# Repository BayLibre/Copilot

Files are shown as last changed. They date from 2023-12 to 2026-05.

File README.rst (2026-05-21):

Copilot
=======

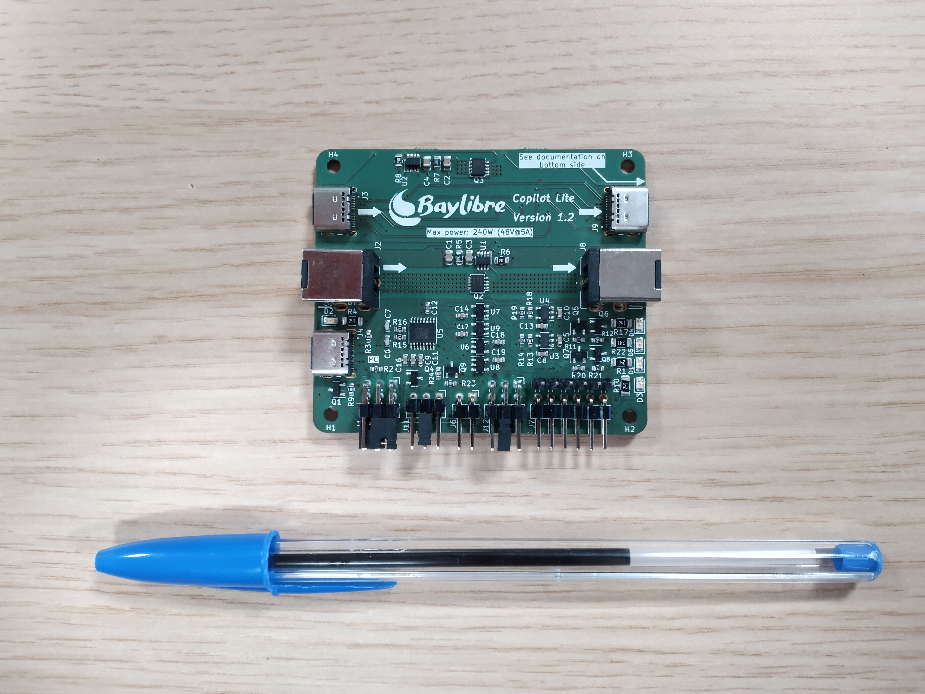
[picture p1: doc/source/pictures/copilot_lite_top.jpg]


Description
-----------

The user documentation is available in the ``doc`` folder.
The generated HTML pages can be viewed `here <https://baylibre.github.io/Copilot/>`_.

The board hardware files are in the ``Copilot_Lite/Hardware`` folder.

The FTDI chip is configured and serialized by the ``Serialization`` software located in the  ``Copilot_Lite/Software`` folder.
The boards serialization and test procedure is described in the ``Copilot_Lite/Factory_Testing.md`` file.

Doc build instructions
----------------------

Using python3, do:

.. code-block:: console

   $ pip3 install -U sphinx sphinx-rtd-theme sphinx-prompt

Then rebuild with:

.. code-block:: console

   $ cd doc
   $ make html

The build output is located in ``doc/build/html/``. Open it with:

.. code-block:: console

   $ xdg-open doc/build/html/index.html

Tips and tricks
---------------

To find a reference to another section, use:

.. code-block:: console

   $ python -m sphinx.ext.intersphinx doc/build/html/objects.inv

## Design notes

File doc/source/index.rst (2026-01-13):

.. Copilot documentation master file, created by
   sphinx-quickstart on Tue Dec 12 19:07:24 2023.
   You can adapt this file completely to your liking, but it should at least
   contain the root `toctree` directive.

Welcome to Copilot's documentation!
===================================

Copilot is a small device used to control the power and UART of a Device Under
Test (DUT). Copilot is controlled and powered by a PC using a single USB-C
connection. It controls the DUT power supply through either another USB-C
connection or a barrel jack connection.

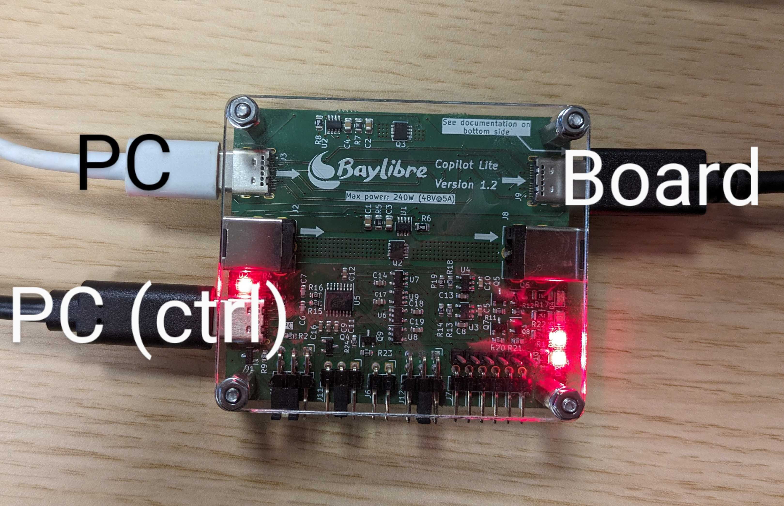
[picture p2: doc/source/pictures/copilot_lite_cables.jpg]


Features
--------

 - Power switching with a simple command available in many distributions:

   .. prompt:: bash

     gpioset /dev/copilot/by-id/${ID_USB_SERIAL_SHORT}/gpiochip 0=1

 - Switch power up to 48V/5A via USB-C or Power Jack
 - Connect to DUT UART on 1.8/3.3/5V
 - Provide 3 additional GPIOs for other DUT related tasks

.. toctree::
   :maxdepth: 2
   :caption: Documentation:

   getting-started
   tips-and-tricks
   technical-information

Indices and tables
==================

* :ref:`genindex`
* :ref:`modindex`
* :ref:`search`

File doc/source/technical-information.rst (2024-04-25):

Technical information
=====================

Barrel jack power channel
-------------------------

- The Barrel jack power channel is rated for 48V @ 5A without additional
  cooling (at a normal room temperature). A higher power **has not been
  tested** and might blow up your Copilot board, it also may need additional
  cooling.
- The barrel jacks dimensions are 2.1x5.5mm.
- Connectors polarity: the barrel jack outer contact is GND, the center pin is
  a positive voltage.
- Voltage polarity must not be reversed, and a negative voltage on the barrel
  jack center pin is forbidden.
- The minimum allowed voltage on this channel is +5V.
- If a voltage greater than or equal to 53.3V is applied to the jack channel,
  the power transistor will open thanks to an overvoltage protection. The
  Copilot board needs to be fully reset to be used again (by removing all jack
  and USB-C cables connected to the Copilot board and then reconnecting them).

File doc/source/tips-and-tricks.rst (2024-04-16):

Tips and tricks
===============

Creating your own jack cable
----------------------------

Given the differences between barrel jack connectors (both the inside and
outside diameter) and the difficulty distinguishing between them, it may
make more sense to create a custom cable.

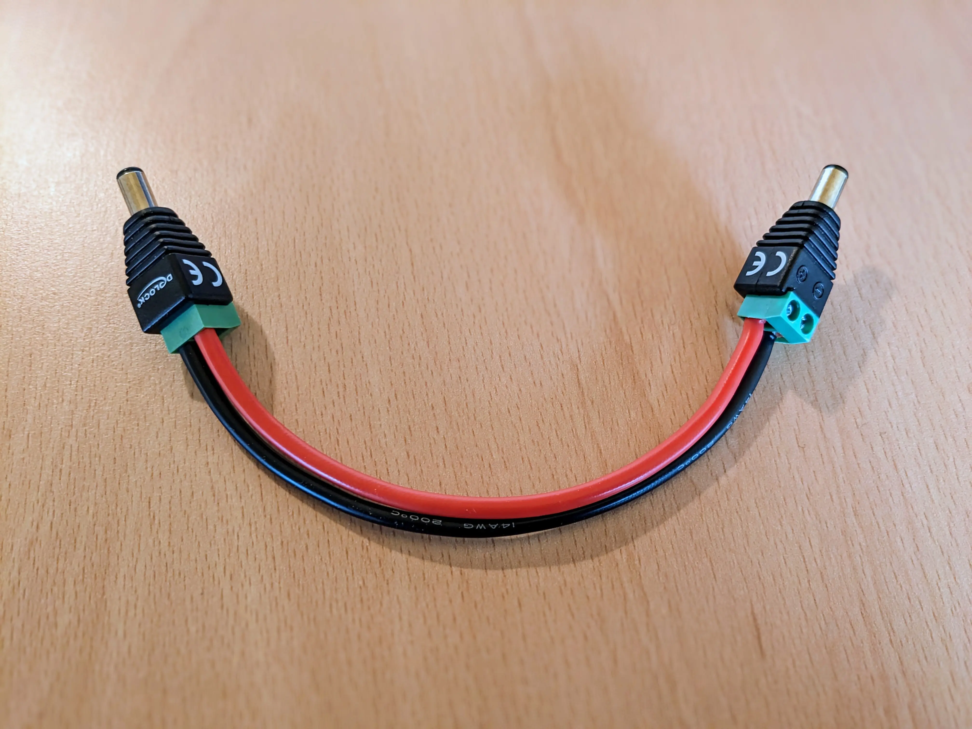
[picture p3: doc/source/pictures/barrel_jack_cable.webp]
   

For example, a cable can be created using two barrel jack male connectors with
screw terminals. It is possible for some 2.1x5.5mm barrel jack connectors to also
work with 2.5x5.5mm female connectors.

The recommended diameter of the wire connecting the two adapters is 2.5mm² or
14 AWG, so that they will be able to carry the power with a minimized
resistance. You are of course free to use whatever cable you want that suits
your needs according to the load you are powering.

It is also recommended to keep the cable length as short as possible for the
designated task to minimize its resistance.

The connector ``CLEVER LITTLE BOX CLB-JL-52Y`` has been tested and holds up to
250W without issue or too much overheating.

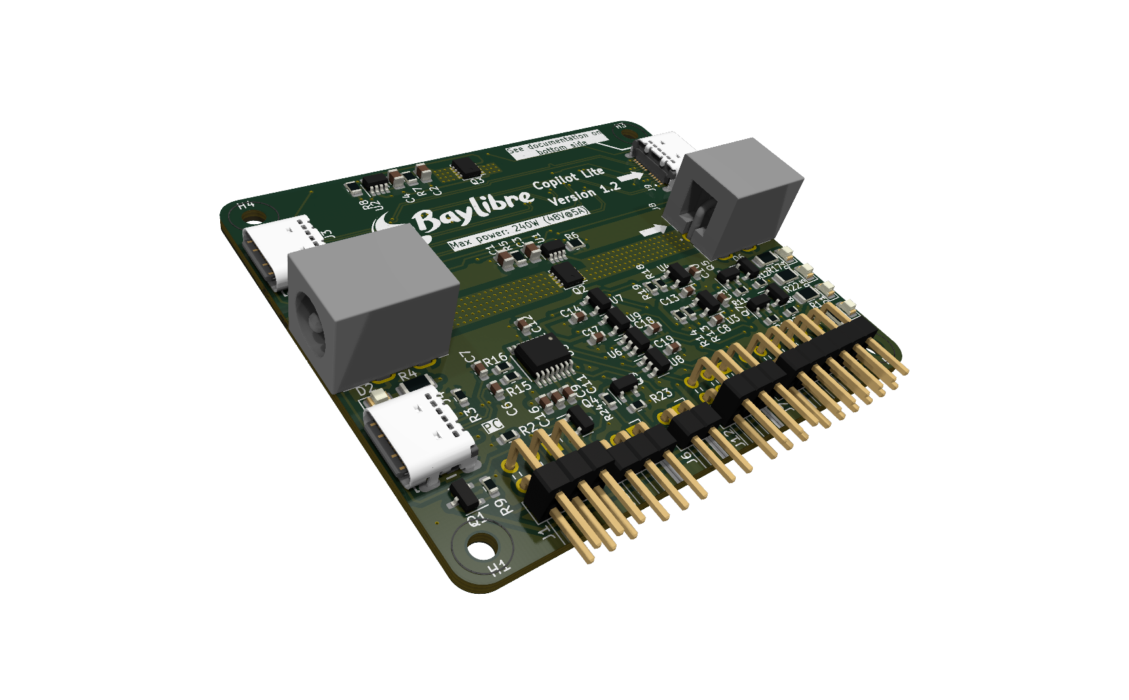
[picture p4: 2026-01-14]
doc/source/pictures/copilot_lite_3d_side.png

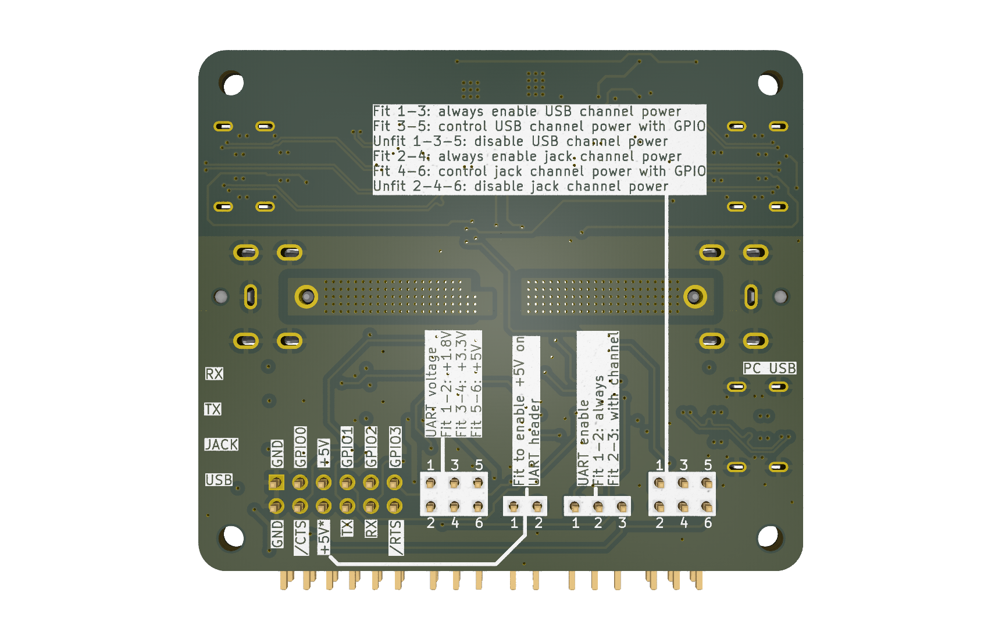
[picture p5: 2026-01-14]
doc/source/pictures/copilot_lite_3d_bottom.png

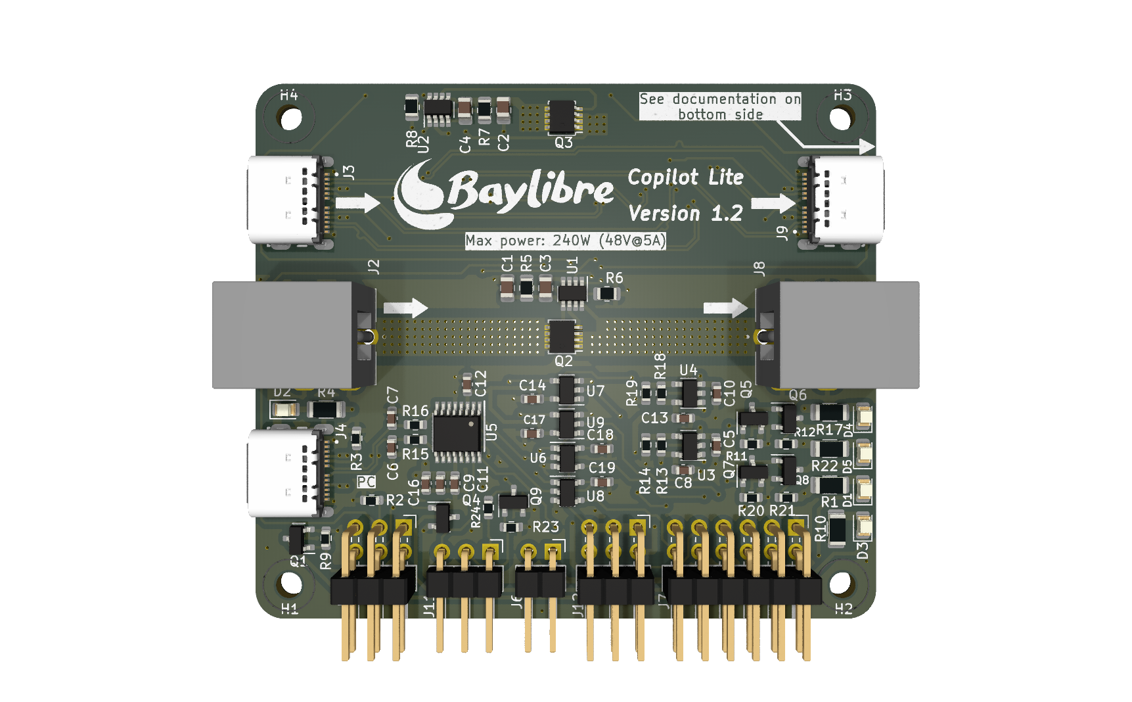
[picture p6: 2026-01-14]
doc/source/pictures/copilot_lite_3d_top.png

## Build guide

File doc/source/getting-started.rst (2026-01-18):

Getting started
===============

Hardware setup
--------------

To use Copilot, you need:

- A Copilot
- 1 USB-C cable for control (only USB2 wiring needed)

Optionally, depending on your needs:

- 2 USB-C cables for power (power supply ↔ Copilot ↔ DUT)
- 2 Barrel jack cables for additional power supply
- 3+ wires for FTDI (debug UART)
- Wires for additional GPIOs

Plug it in as following:



.. note::

   By default, the USB and barrel jack power passthroughs are controlled by a
   single GPIO. To enable the USB and barrel jack power passthroughs follow
   the steps in :ref:`Switch power`.

.. warning::

   Even if USB-C is a **reversible** connector, the USB-C cables can only work
   in **one direction**.  If USB power supply seems not working after enabling.
   Try flipping one USB-C cable on either ``J9`` or ``J3``.

.. warning::

   Copilot is not designed to support power passthrough through the USB and
   barrel jack connectors at the same time. It is therefore good practice to
   only jump a single pair of pins at a time

Basic documentation has been silk screened onto both sides of the board.

Design files, along with the latest schematics and the interactive BOM,
are manually generated for each release and available on the
`releases page <https://github.com/BayLibre/Copilot/releases>`_.
The interactive BOM features an annotated diagram of the board
including the silk screen, both sides of the board and searchable references.

Udev rules
----------

Generally, a PC running Linux has multiple GPIOs in the system. To easily
identify Copilot, create some user-friendly symlinks with udev as follows.

#. Add the ``/etc/udev/rules.d/70-copilot.rules`` udev rules to your system:

   .. code-block::

     ACTION=="remove", GOTO="copilot_end"

     # Match Copilot USB devices
     SUBSYSTEMS=="usb", ATTRS{manufacturer}=="Bay[lL]ibre", ATTRS{product}=="Bay[lL]ibre Copilot*", ENV{IS_COPILOT}="1", ENV{ID_USB_SERIAL_SHORT}="$attr{serial}"
     # Enable Copilot gpio access via uaccess and copilot symlink
     ENV{IS_COPILOT}=="1", SUBSYSTEMS=="gpio", MODE="0660", SYMLINK+="copilot/by-id/$env{ID_USB_SERIAL_SHORT}/gpiochip", TAG+="uaccess"
     # Create Copilot tty symlink
     ENV{IS_COPILOT}=="1", SUBSYSTEMS=="tty", SYMLINK+="copilot/by-id/$env{ID_USB_SERIAL_SHORT}/tty"

     LABEL="copilot_end"

   .. note::

     For users who rely on the ``plugdev`` group, use the following rules
     instead:

     .. code-block::

         # Match Copilot USB devices
         SUBSYSTEMS=="usb", ATTRS{manufacturer}=="Bay[lL]ibre", ATTRS{product}=="Bay[lL]ibre Copilot*", ENV{IS_COPILOT}="1", ENV{ID_USB_SERIAL_SHORT}="$attr{serial}"
         # Enable Copilot gpio access for the plugdev group and copilot symlink
         ENV{IS_COPILOT}=="1", SUBSYSTEMS=="gpio", MODE="0660", GROUP="plugdev", SYMLINK+="copilot/by-id/$env{ID_USB_SERIAL_SHORT}/gpiochip"
         # Create Copilot tty symlink
         ENV{IS_COPILOT}=="1", SUBSYSTEMS=="tty", SYMLINK+="copilot/by-id/$env{ID_USB_SERIAL_SHORT}/tty"

     ``uaccess`` should be used instead of ``plugdev``. For more information,
     see: https://github.com/systemd/systemd/issues/4288

#. Reload the udev rules with:

  .. prompt:: bash $

     sudo udevadm control --reload
     sudo udevadm trigger

This creates an entry in ``/dev/copilot/by-id/<copilot_id>`` where
``<copilot_id>`` is an unique serial number.

.. _Switch power:

Switch power
------------

Now that the udev rules have been installed, we can interact with Copilot using the
standard ``libgpiod-utils``, such as ``gpioset``.

Start by finding the serial number for your Copilot (e.g. ``D30HF04Y``) and
export it as an environment variable:

.. prompt:: bash $ auto

   $ tree /dev/copilot/
   /dev/copilot/
   └── by-id
       └── D30HF04Y
           ├── gpiochip -> ../../../gpiochip0
           └── tty -> ../../../ttyUSB1
   $ export ID_USB_SERIAL_SHORT="D30HF04Y"

Power over the USB and barrel jack connectors may be independently configured
using the J1 header to be either controlled by a single shared GPIO or always
passthrough power. See the silk screen at the top of the rear side of the
board.

By default, the USB and barrel jack power passthroughs are controlled by your
PC using a single GPIO that is disabled after power cycling Copilot. The
passthroughs can be powered by enabling the GPIO as follows:

.. prompt:: bash $

   gpioset --hold-period=20ms -t0 --chip /dev/copilot/by-id/${ID_USB_SERIAL_SHORT}/gpiochip 0=1

.. note::

   For older versions of ``libgpiod-utils``, (before v2.0), use the following
   instead:

   .. prompt:: bash $

      gpioset /dev/copilot/by-id/${ID_USB_SERIAL_SHORT}/gpiochip 0=1

To disable the barrel jack power passthrough, use ``0=0`` instead:

.. prompt:: bash $

   gpioset --hold-period=20ms -t0 --chip /dev/copilot/by-id/${ID_USB_SERIAL_SHORT}/gpiochip 0=0

Helper script
~~~~~~~~~~~~~

``copilot.sh`` is an example helper script which can either reboot or power off
a board connected to Copilot.

It can be used with:

.. prompt:: bash $ auto

   # to reboot
   $ copilot.sh reboot
   # to poweroff
   $ copilot.sh poweroff

The contents of ``copilot.sh`` could be as following:

.. code-block:: bash

   #!/bin/bash

   # Set a default value, but don't overwrite ID_USB_SERIAL_SHORT
   # if it's already set
   : ${ID_USB_SERIAL_SHORT:="D30HF04Y"}

   usage()
   {
       echo "Usage: ${0##*/} reboot|poweroff"
   }

   if [[ $# -ne 1 ]]; then
       usage
       exit 1
   fi

   do_poweroff()
   {
       gpioset --hold-period=20ms -t0 --chip /dev/copilot/by-id/${ID_USB_SERIAL_SHORT}/gpiochip 0=0
       # or for libgpiod v < 2.0
       #gpioset /dev/copilot/by-id/${ID_USB_SERIAL_SHORT}/gpiochip 0=0
   }

   do_poweron()
   {
       gpioset --hold-period=20ms -t0 --chip /dev/copilot/by-id/${ID_USB_SERIAL_SHORT}/gpiochip 0=1
       # or for libgpiod v < 2.0
       #gpioset /dev/copilot/by-id/${ID_USB_SERIAL_SHORT}/gpiochip 0=1
   }

   do_reboot()
   {
       do_poweroff
       # maybe wait until all power drained from the board
       #sleep 5
       do_poweron
   }

   case "$1" in
       "reboot") do_reboot;;
       "poweroff") do_poweroff;;
       *) usage; exit 1;;

   esac

Connect to a UART
-----------------

Connect to the Copilot UART using the left-most header at the bottom of
the PCB (J4). The pins are documented on the bottom of the PCB. The voltage can
be selected on the next header.

To use the connected UART in Linux you can use your favorite terminal program
with the device ``/dev/copilot/by-id/${ID_USB_SERIAL_SHORT}/tty``, in this
example we are using ``tio``:

.. prompt:: bash

   tio /dev/copilot/by-id/${ID_USB_SERIAL_SHORT}/tty

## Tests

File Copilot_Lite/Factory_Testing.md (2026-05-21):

# Factory testing

The board comes from the factory, fully assembled but without any jumper.  

The test setup is made of :

* A Linux PC running Debian
* An USB 3.x/2.0 hub.
* Two USB-C cables, one of them being *USB 3.x* compliant. The second one can be only *USB 2.0* compliant.

## Serialization
1. On the PC, run `sudo dmesg -wH` in a terminal.
2. Connect the PC to the board `PC USB (J4)` connector through an USB-C cable (the cable can either be *USB 3.x* or *USB 2.0* compliant).
    1. The `PC USB (D2)` LED must light.
    2. The PC must detect a `FT230X Basic UART`.
3. Disconnect the USB-C cable from the board only, flip it face-to-down and reconnect it to the board `PC USB` connector. The result must be identical to the previous step.
4. Run the serialization tool with the command `sudo Copilot/Copilot_Lite/Software/Serialization/copilot-lite-serialize`.
5. Disconnect and reconnect the USB-C cable from the board `PC USB` connector. The `dmesg` output must now display a `BayLibre Copilot Lite Vx.y` product.
6. Make sure that the serialized version is matching the version written on the board PCB silkscreen.

You can close the terminal displaying the kernel console output once all boards have been successfully serialized.

## USB 3.0 passthrough

1. On the PC, run `sudo dmesg -wH | grep -i -e superspeed -e high-speed` in a terminal.
2. Fit a jumper between pins 1 and 3 of the board `J1` pin header.
3. Connect the board `PC USB (J4)` connector to the PC with an USB-C cable.
    1. The `PC USB (D2)` LED must light.
    2. The `USB (D3)` LED must light.
4. Connect an *USB 3.x* USB hub to the `J9` USB-C connector.
5. Connect a second USB-C cable from the PC to the board `J3` USB-C connector. Note that the cable **must** be *USB 3.x* compliant in order to the whether the board *USB 3.0* SuperSpeed pairs are working.
6. There are only two board USB-C connectors orientation that allow the power and the data to go through. Flip the `J3` and the `J9` cable orientation one after the other, the USB hub must be detected in two of the four possible combinations.
7. Each time that the USB hub is detected, make sure that the PC kernel console is detecting both *SuperSpeed* and *high-speed* internal USB hubs. This proves that either the *USB 3.0* and the *USB 2.0* board signals are working.

## Connecting jumpers

1. Remove any testing jumper from the board.
2. `J1` pin header :
    1. Fit a jumper horizontally between pins 3 and 5.
    2. Fit a jumper horizontally between pins 4 and 6.
3. `J11` pin header :
    1. Fit a jumper horizontally between pins 2 and 3.
4. `J12` pin header :
    1. Fit a jumper vertically between pins 3 and 4.

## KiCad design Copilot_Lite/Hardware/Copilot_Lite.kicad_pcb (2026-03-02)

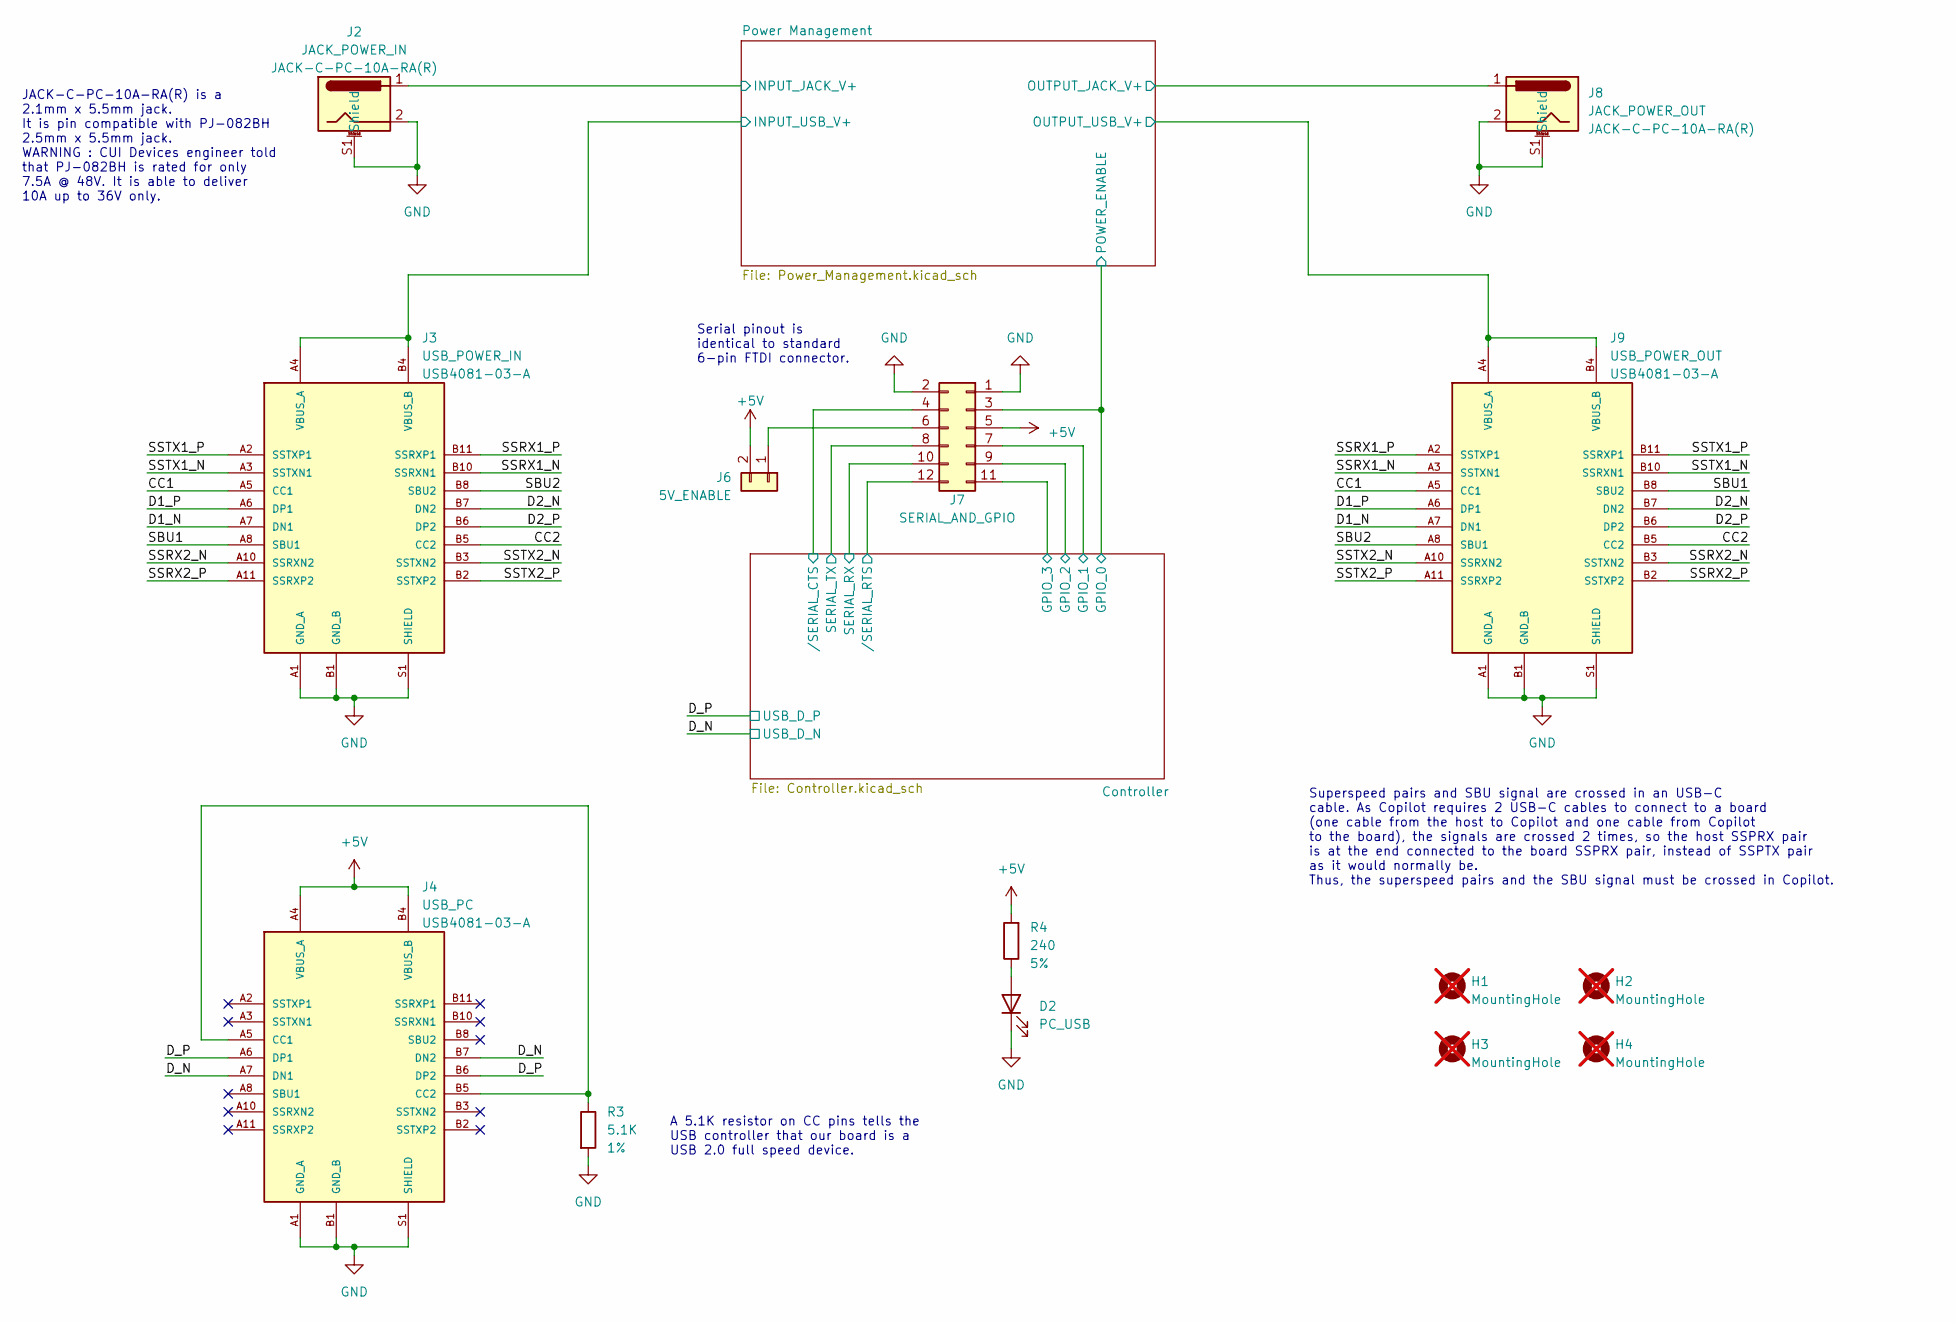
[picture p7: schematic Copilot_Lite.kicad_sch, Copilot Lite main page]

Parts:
D2: PC_USB; LED_0805_2012Metric; PartNumber 150080SS75000
H1, H2, H3, H4: MountingHole; MountingHole_2.7mm; not fitted
J2: JACK_POWER_IN; JACK-C-PC-10A-RA(R); PartNumber JACK-C-PC-10A-RA(R)
J3: USB_POWER_IN; USB4081-03-A; PartNumber USB4081-03-A
J4: USB_PC; USB4081-03-A; PartNumber USB4081-03-A
J6: 5V_ENABLE; PinHeader_1x02_P2.54mm_Horizontal
J7: SERIAL_AND_GPIO; PinHeader_2x06_P2.54mm_Horizontal
J8: JACK_POWER_OUT; JACK-C-PC-10A-RA(R); PartNumber JACK-C-PC-10A-RA(R)
J9: USB_POWER_OUT; USB4081-03-A; PartNumber USB4081-03-A
R3: 5.1K; R_0603_1608Metric; PartNumber RC0603FR-075K1L
R4: 240; R_1206_3216Metric; PartNumber RC1206JR-07240RL

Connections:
+5V: J4.A4 (VBUS_A), J4.A9 (VBUS_A), J4.B4 (VBUS_B), J4.B9 (VBUS_B), J6.2, J7.5, R4.2; also elsewhere on the board
/CC1: J3.A5 (CC1), J9.A5 (CC1)
/CC2: J3.B5 (CC2), J9.B5 (CC2)
/Controller/GPIO_0: J7.3; also elsewhere on the board
/Controller/GPIO_1: J7.7; also elsewhere on the board
/Controller/GPIO_2: J7.9; also elsewhere on the board
/Controller/GPIO_3: J7.11; also elsewhere on the board
/Controller/SERIAL_RX: J7.10; also elsewhere on the board
/Controller/SERIAL_TX: J7.8; also elsewhere on the board
/Controller//SERIAL_CTS: J7.4; also elsewhere on the board
/Controller//SERIAL_RTS: J7.12; also elsewhere on the board
/D1_N: J3.A7 (DN1), J9.A7 (DN1)
/D1_P: J3.A6 (DP1), J9.A6 (DP1)
/D2_N: J3.B7 (DN2), J9.B7 (DN2)
/D2_P: J3.B6 (DP2), J9.B6 (DP2)
/D_N: J4.A7 (DN1), J4.B7 (DN2); also elsewhere on the board
/D_P: J4.A6 (DP1), J4.B6 (DP2); also elsewhere on the board
/Power Management/INPUT_JACK_V+: J2.1; also elsewhere on the board
/Power Management/INPUT_USB_V+: J3.A4 (VBUS_A), J3.A9 (VBUS_A), J3.B4 (VBUS_B), J3.B9 (VBUS_B); also elsewhere on the board
/Power Management/OUTPUT_JACK_V+: J8.1; also elsewhere on the board
/Power Management/OUTPUT_USB_V+: J9.A4 (VBUS_A), J9.A9 (VBUS_A), J9.B4 (VBUS_B), J9.B9 (VBUS_B); also elsewhere on the board
/SBU1: J3.A8 (SBU1), J9.B8 (SBU2)
/SBU2: J3.B8 (SBU2), J9.A8 (SBU1)
/SSRX1_N: J3.B10 (SSRXN1), J9.A3 (SSTXN1)
/SSRX1_P: J3.B11 (SSRXP1), J9.A2 (SSTXP1)
/SSRX2_N: J3.A10 (SSRXN2), J9.B3 (SSTXN2)
/SSRX2_P: J3.A11 (SSRXP2), J9.B2 (SSTXP2)
/SSTX1_N: J3.A3 (SSTXN1), J9.B10 (SSRXN1)
/SSTX1_P: J3.A2 (SSTXP1), J9.B11 (SSRXP1)
/SSTX2_N: J3.B3 (SSTXN2), J9.A10 (SSRXN2)
/SSTX2_P: J3.B2 (SSTXP2), J9.A11 (SSRXP2)
GND: D2.1 (K), J2.2, J2.S1 (Shield), J2.S2 (Shield), J2.S3 (Shield), J2.S4 (Shield), J3.A1 (GND_A), J3.A12 (GND_A), J3.B1 (GND_B), J3.B12 (GND_B), J3.S1 (SHIELD), J3.S2 (SHIELD), J3.S3 (SHIELD), J3.S4 (SHIELD), J3.S5 (SHIELD), J3.S6 (SHIELD), J4.A1 (GND_A), J4.A12 (GND_A), J4.B1 (GND_B), J4.B12 (GND_B), J4.S1 (SHIELD), J4.S2 (SHIELD), J4.S3 (SHIELD), J4.S4 (SHIELD), J4.S5 (SHIELD), J4.S6 (SHIELD), J7.1, J7.2, J8.2, J8.S1 (Shield), J8.S2 (Shield), J8.S3 (Shield), J8.S4 (Shield), J9.A1 (GND_A), J9.A12 (GND_A), J9.B1 (GND_B), J9.B12 (GND_B), J9.S1 (SHIELD), J9.S2 (SHIELD), J9.S3 (SHIELD), J9.S4 (SHIELD), J9.S5 (SHIELD), J9.S6 (SHIELD), R3.2; also elsewhere on the board
unnamed: D2.2 (A), R4.1
unnamed: J4.A5 (CC1), J4.B5 (CC2), R3.1
unnamed: J6.1, J7.6

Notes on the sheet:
A 5.1K resistor on CC pins tells the USB controller that our board is a USB 2.0 full speed device.
JACK-C-PC-10A-RA(R) is a 2.1mm x 5.5mm jack. It is pin compatible with PJ-082BH 2.5mm x 5.5mm jack. WARNING : CUI Devices engineer told that PJ-082BH is rated for only 7.5A @ 48V. It is able to deliver 10A up to 36V only.
Superspeed pairs and SBU signal are crossed in an USB-C cable. As Copilot requires 2 USB-C cables to connect to a board (one cable from the host to Copilot and one cable from Copilot to the board), the signals are crossed 2 times, so the host SSPRX pair is at the end connected to the board SSPRX pa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
Serial pinout is identical to standard 6-pin FTDI connector.

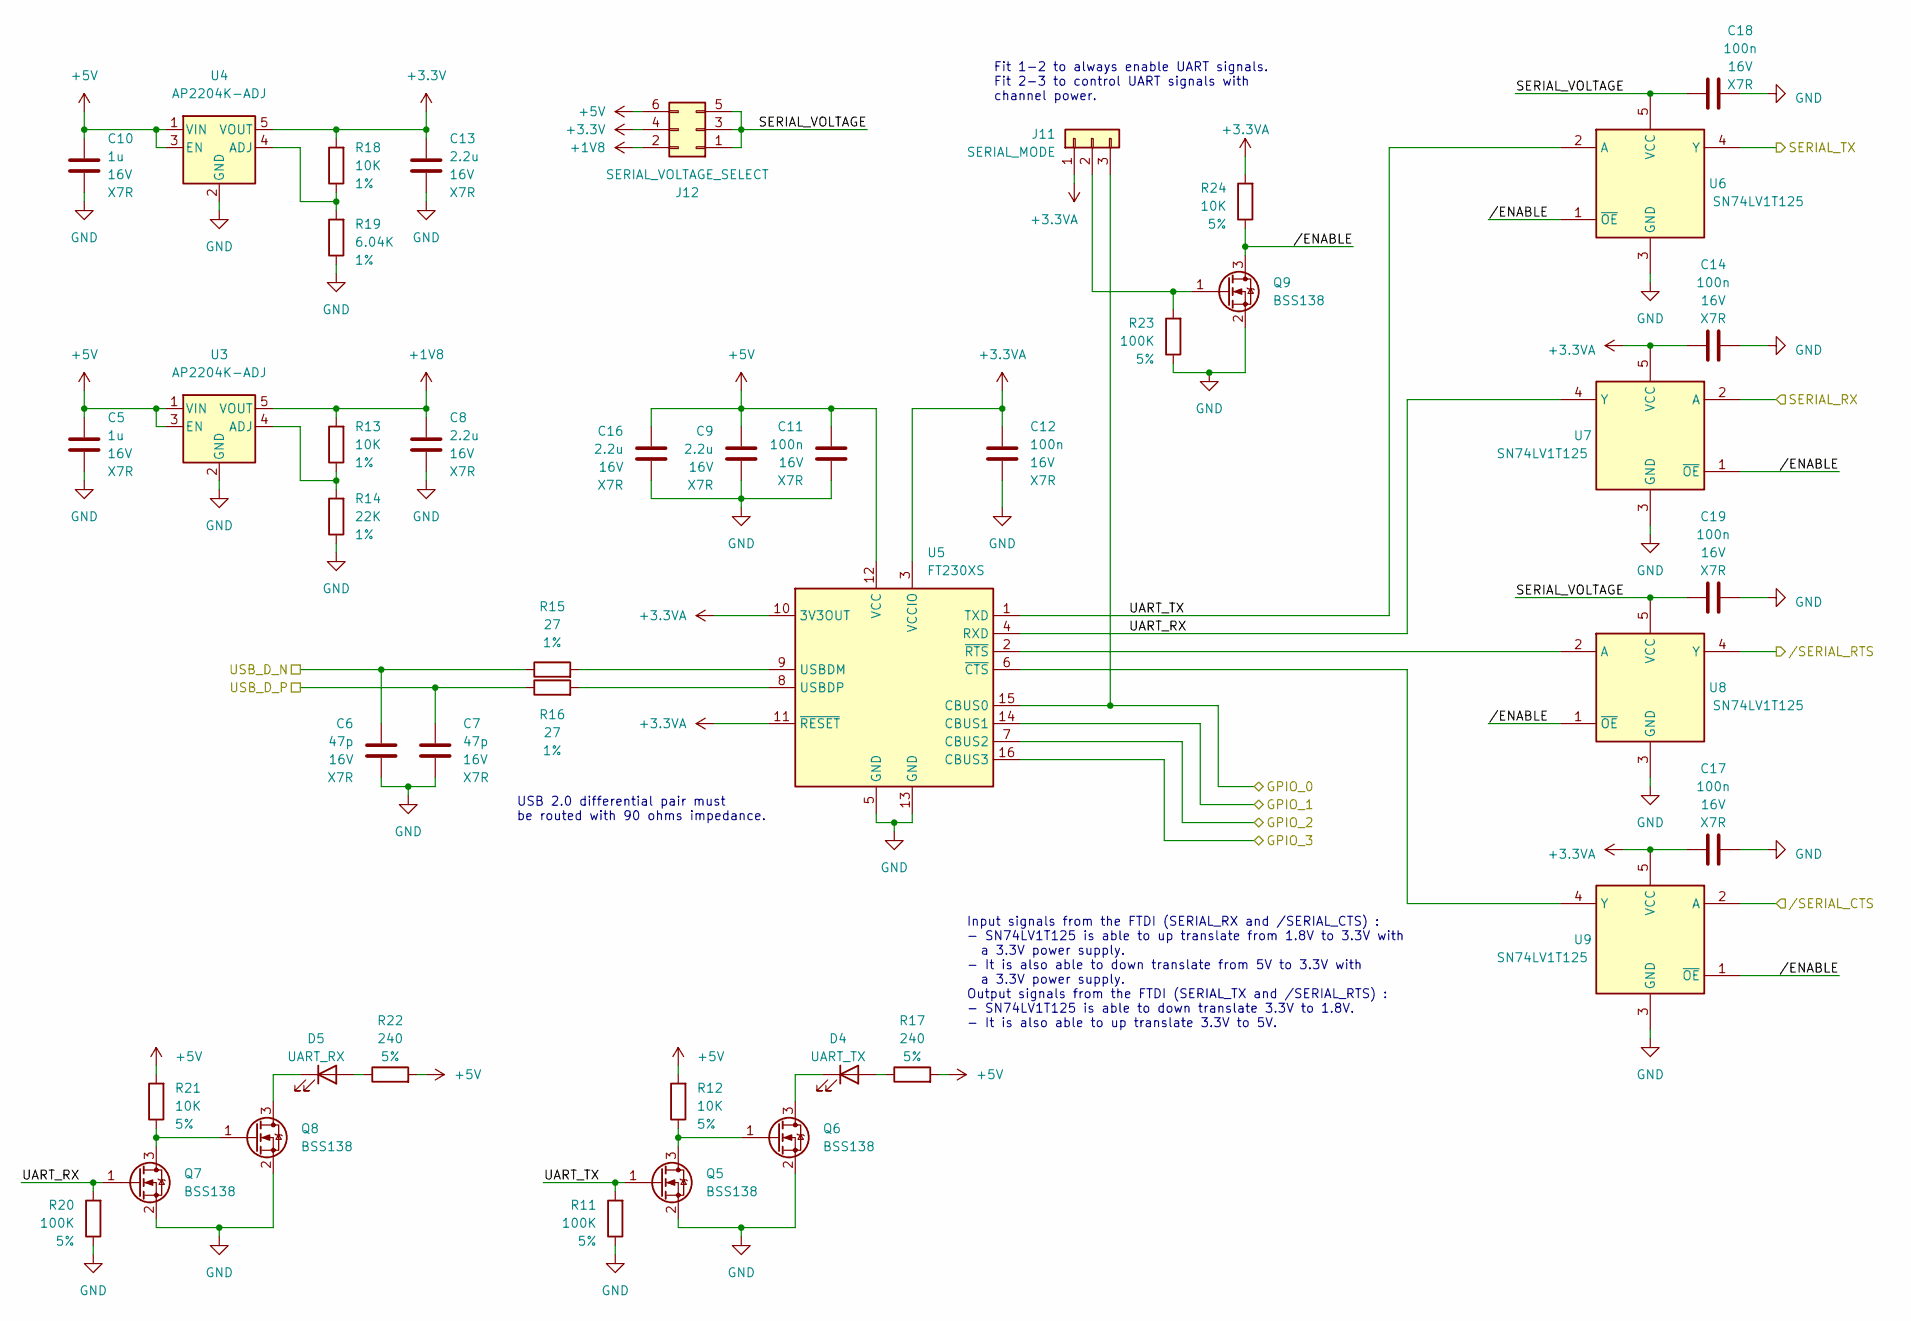
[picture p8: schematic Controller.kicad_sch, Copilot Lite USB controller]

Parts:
C5, C10: 1u; C_0603_1608Metric; PartNumber CL10A105KO8NNNC
C6, C7: 47p; C_0603_1608Metric; PartNumber CL10C470JB81PNC
C8, C9, C13, C16: 2.2u; C_0603_1608Metric; PartNumber CL10A225KO8NNNC
C11, C12, C14, C17, C18, C19: 100n; C_0603_1608Metric; PartNumber CL10B104KO8NNNC
D4: UART_TX; LED_0805_2012Metric; PartNumber 150080SS75000
D5: UART_RX; LED_0805_2012Metric; PartNumber 150080SS75000
J11: SERIAL_MODE; PinHeader_1x03_P2.54mm_Horizontal
J12: SERIAL_VOLTAGE_SELECT; PinHeader_2x03_P2.54mm_Horizontal
Q5, Q6, Q7, Q8, Q9: BSS138; SOT-23; PartNumber BSS138P,215
R11, R20, R23: 100K; R_0603_1608Metric; PartNumber RC0603FR-07100KL
R12, R13, R18, R21, R24: 10K; R_0603_1608Metric; PartNumber RNCP0603FTD10K0
R14: 22K; R_0603_1608Metric; PartNumber RC0603FR-0722KL
R15, R16: 27; R_0603_1608Metric; PartNumber RC0603FR-1327RL
R17, R22: 240; R_1206_3216Metric; PartNumber RC1206JR-07240RL
R19: 6.04K; R_0603_1608Metric; PartNumber RC0603FR-076K04L
U3, U4: AP2204K-ADJ; SOT-23-5; PartNumber AP2204K-ADJTRG1
U5: FT230XS; SSOP-16_3.9x4.9mm_P0.635mm; PartNumber FT230XS-R
U6, U7, U8, U9: SN74LV1T125; SOT-23-5; PartNumber SN74LV1T125DBV

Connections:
+1V8: C8.1, J12.2, R13.2, U3.5 (VOUT)
+3.3V: C13.1, J12.4, R18.2, U4.5 (VOUT)
+3.3VA: C12.1, C14.1, C17.1, J11.1, R24.2, U5.3 (VCCIO), U5.10 (3V3OUT), U5.11 (~RESET), U7.5 (VCC), U9.5 (VCC)
+5V: C5.1, C9.1, C10.1, C11.1, C16.1, J12.6, R12.2, R17.2, R21.2, R22.2, U3.1 (VIN), U3.3 (EN), U4.1 (VIN), U4.3 (EN), U5.12 (VCC); also elsewhere on the board
/Controller/GPIO_0: J11.3, U5.15 (CBUS0); also elsewhere on the board
/Controller/GPIO_1: U5.14 (CBUS1); also elsewhere on the board
/Controller/GPIO_2: U5.7 (CBUS2); also elsewhere on the board
/Controller/GPIO_3: U5.16 (CBUS3); also elsewhere on the board
/Controller/SERIAL_RX: U7.2 (A); also elsewhere on the board
/Controller/SERIAL_TX: U6.4 (Y); also elsewhere on the board
/Controller/SERIAL_VOLTAGE: C18.1, C19.1, J12.1, J12.3, J12.5, U6.5 (VCC), U8.5 (VCC)
/Controller/UART_RX: Q7.1 (G), R20.2, U5.4 (RXD), U7.4 (Y)
/Controller/UART_TX: Q5.1 (G), R11.2, U5.1 (TXD), U6.2 (A)
/Controller//ENABLE: Q9.3 (D), R24.1, U6.1 (~OE), U7.1 (~OE), U8.1 (~OE), U9.1 (~OE)
/Controller//SERIAL_CTS: U9.2 (A); also elsewhere on the board
/Controller//SERIAL_RTS: U8.4 (Y); also elsewhere on the board
/D_N: C6.1, R15.1; also elsewhere on the board
/D_P: C7.1, R16.1; also elsewhere on the board
GND: C5.2, C6.2, C7.2, C8.2, C9.2, C10.2, C11.2, C12.2, C13.2, C14.2, C16.2, C17.2, C18.2, C19.2, Q5.2 (S), Q6.2 (S), Q7.2 (S), Q8.2 (S), Q9.2 (S), R11.1, R14.1, R19.1, R20.1, R23.1, U3.2 (GND), U4.2 (GND), U5.5 (GND), U5.13 (GND), U6.3 (GND), U7.3 (GND), U8.3 (GND), U9.3 (GND); also elsewhere on the board
unnamed: D4.2 (A), R17.1
unnamed: D4.1 (K), Q6.3 (D)
unnamed: D5.2 (A), R22.1
unnamed: D5.1 (K), Q8.3 (D)
unnamed: J11.2, Q9.1 (G), R23.2
unnamed: Q5.3 (D), Q6.1 (G), R12.1
unnamed: Q7.3 (D), Q8.1 (G), R21.1
unnamed: R13.1, R14.2, U3.4 (ADJ)
unnamed: R18.1, R19.2, U4.4 (ADJ)
unnamed: R15.2, U5.9 (USBDM)
unnamed: R16.2, U5.8 (USBDP)
unnamed: U5.6 (~CTS), U9.4 (Y)
unnamed: U5.2 (~RTS), U8.2 (A)

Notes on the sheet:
Input signals from the FTDI (SERIAL_RX and /SERIAL_CTS) : - SN74LV1T125 is able to up translate from 1.8V to 3.3V with a 3.3V power supply. - It is also able to down translate from 5V to 3.3V with a 3.3V power supply. Output signals from the FTDI (SERIAL_TX and /SERIAL_RTS) : - SN74LV1T125 is able 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
USB 2.0 differential pair must be routed with 90 ohms impedance.
Fit 1-2 to always enable UART signals. Fit 2-3 to control UART signals with channel power.

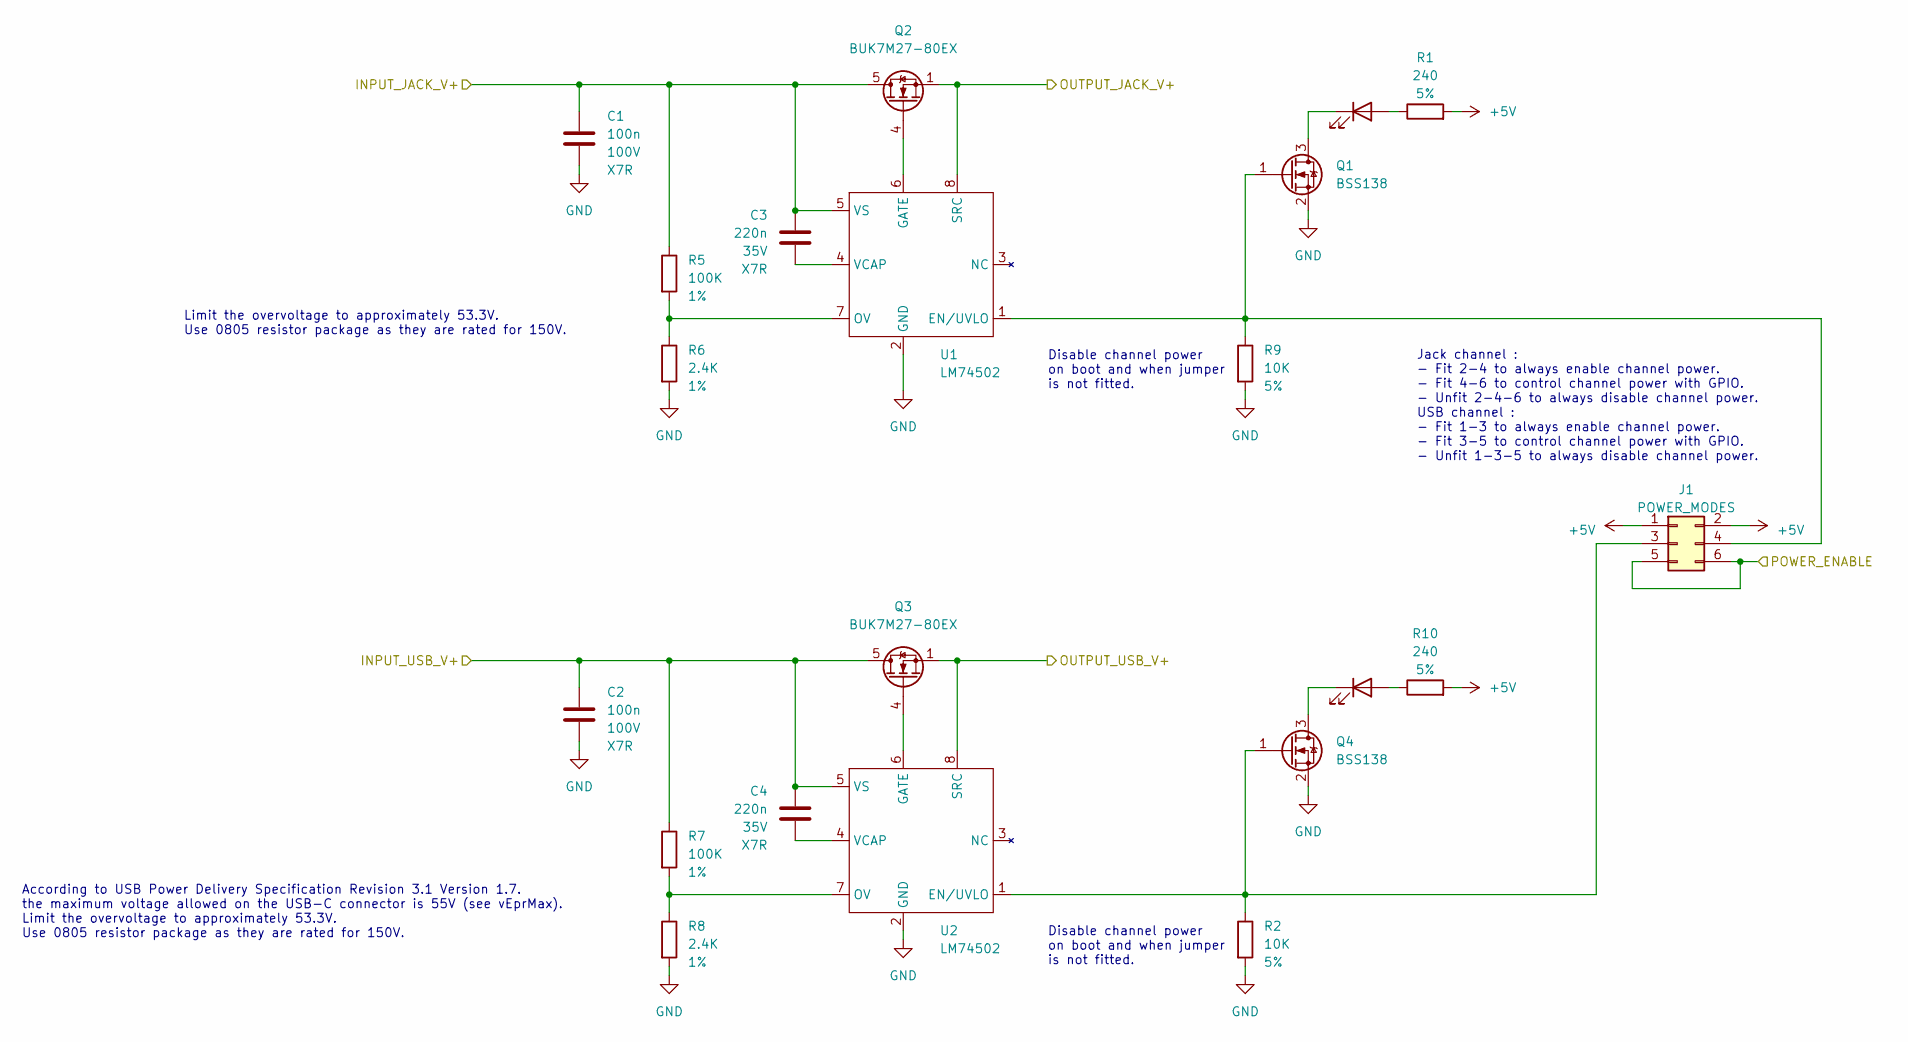
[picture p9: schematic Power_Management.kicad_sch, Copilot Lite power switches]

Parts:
C1, C2: 100n; C_0805_2012Metric; PartNumber CL21B104KCFNNNE
C3, C4: 220n; C_0805_2012Metric; PartNumber CL21B224KBFNNNE
D1, D3: POWER_SWITCH; LED_0805_2012Metric; PartNumber 150080SS75000
J1: POWER_MODES; PinHeader_2x03_P2.54mm_Horizontal
Q1, Q4: BSS138; SOT-23; PartNumber BSS138P,215
Q2, Q3: BUK7M27-80EX; LFPAK33; PartNumber BUK7M27-80EX
R1, R10: 240; R_1206_3216Metric; PartNumber RC1206JR-07240RL
R2, R9: 10K; R_0603_1608Metric; PartNumber RNCP0603FTD10K0
R5, R7: 100K; R_0805_2012Metric; PartNumber RMCF0805FT100K
R6, R8: 2.4K; R_0805_2012Metric; PartNumber RC0805FR-072K4L
U1, U2: LM74502; SOT-23-8; PartNumber LM74502DDFR

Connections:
+5V: J1.1, J1.2, R1.2, R10.2; also elsewhere on the board
/Controller/GPIO_0: J1.5, J1.6; also elsewhere on the board
/Power Management/INPUT_JACK_V+: C1.1, C3.1, Q2.5 (D), R5.1, U1.5 (VS); also elsewhere on the board
/Power Management/INPUT_USB_V+: C2.1, C4.1, Q3.5 (D), R7.1, U2.5 (VS); also elsewhere on the board
/Power Management/OUTPUT_JACK_V+: Q2.1 (S), Q2.2 (S), Q2.3 (S), U1.8 (SRC); also elsewhere on the board
/Power Management/OUTPUT_USB_V+: Q3.1 (S), Q3.2 (S), Q3.3 (S), U2.8 (SRC); also elsewhere on the board
GND: C1.2, C2.2, Q1.2 (S), Q4.2 (S), R2.2, R6.2, R8.2, R9.2, U1.2 (GND), U2.2 (GND); also elsewhere on the board
unnamed: D1.2 (A), R1.1
unnamed: D1.1 (K), Q1.3 (D)
unnamed: D3.2 (A), R10.1
unnamed: D3.1 (K), Q4.3 (D)
unnamed: J1.3, Q4.1 (G), R2.1, U2.1 (EN/UVLO)
unnamed: J1.4, Q1.1 (G), R9.1, U1.1 (EN/UVLO)
unnamed: Q2.4 (G), U1.6 (GATE)
unnamed: Q3.4 (G), U2.6 (GATE)
unnamed: R5.2, R6.1, U1.7 (OV)
unnamed: C3.2, U1.4 (VCAP)
unnamed: R7.2, R8.1, U2.7 (OV)
unnamed: C4.2, U2.4 (VCAP)

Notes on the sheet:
According to USB Power Delivery Specification Revision 3.1 Version 1.7. the maximum voltage allowed on the USB-C connector is 55V (see vEprMax). Limit the overvoltage to approximately 53.3V. Use 0805 resistor package as they are rated for 150V.
Disable channel power on boot and when jumper is not fitted.
Jack channel : - Fit 2-4 to always enable channel power. - Fit 4-6 to control channel power with GPIO. - Unfit 2-4-6 to always disable channel power. USB channel : - Fit 1-3 to always enable channel power. - Fit 3-5 to control channel power with GPIO. - Unfit 1-3-5 to always disable channel power.
Limit the overvoltage to approximately 53.3V. Use 0805 resistor package as they are rated for 150V.

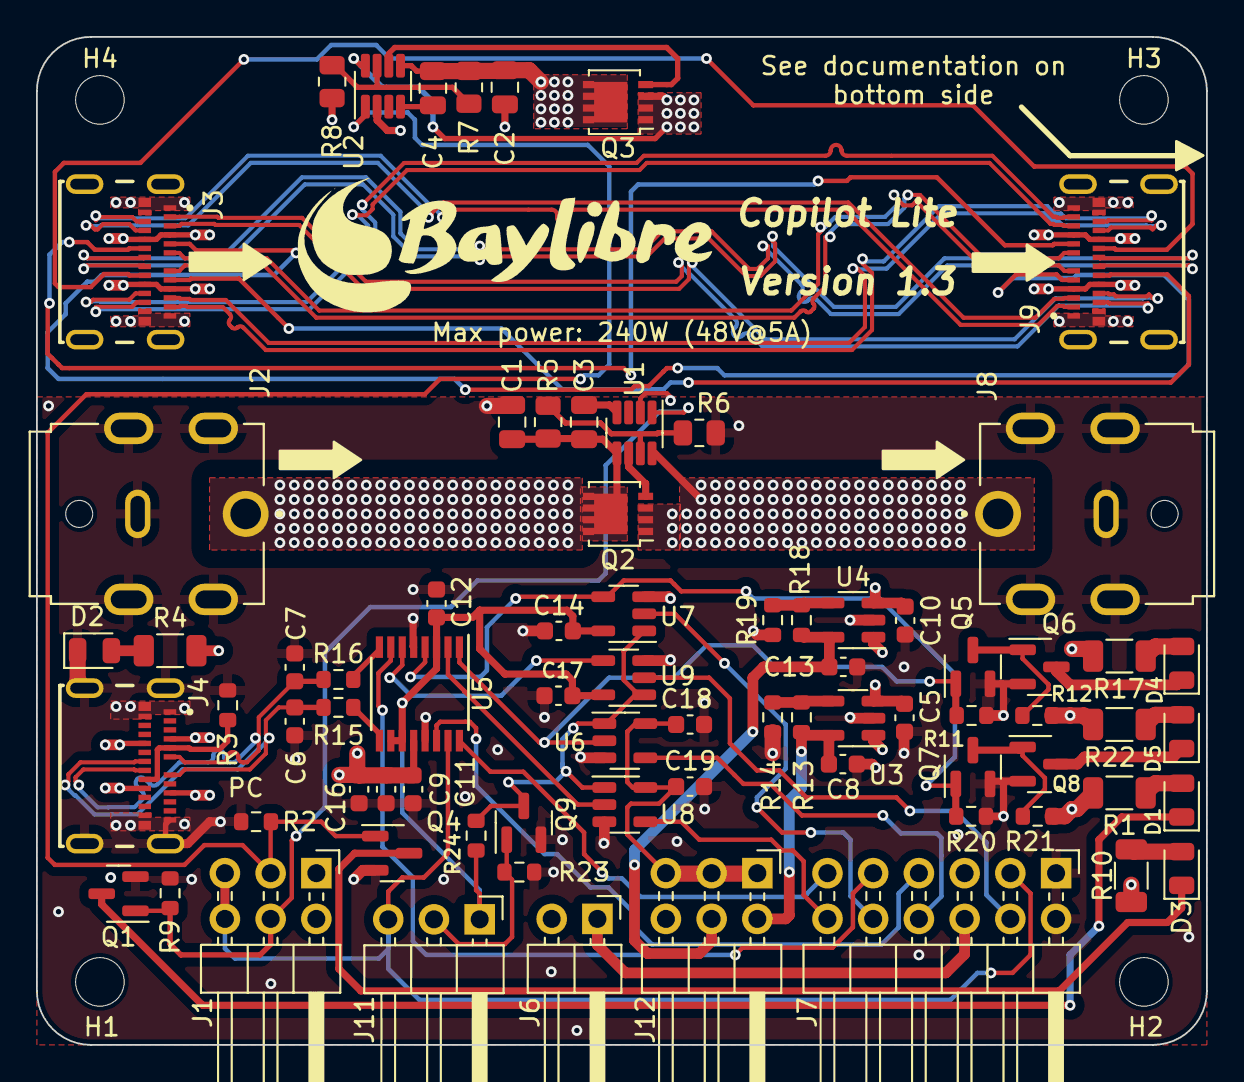
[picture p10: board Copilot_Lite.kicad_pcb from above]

Board: 4 copper layers, 65.0 x 56.0 mm, 79 parts (0 on the bottom side), 67 nets.

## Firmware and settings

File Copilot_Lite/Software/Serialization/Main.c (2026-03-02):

/** @file Main.c
 * Serialize a Copilot Lite EEPROM.
 * @author Adrien RICCIARDI
 */
#include <errno.h>
#include <ftdi.h>
#include <stdint.h>
#include <stdio.h>
#include <stdlib.h>
#include <string.h>
#include <unistd.h>

//-------------------------------------------------------------------------------------------------
// Private constants and macros
//-------------------------------------------------------------------------------------------------
/** Display a message prefixed by the function name and the line.
 * @param Format A printf like format string.
 */
#define LOG(Format, ...) printf("[%s:%d] " Format, __FUNCTION__, __LINE__, ##__VA_ARGS__)

/** FTDI FT230X USB vendor ID. */
#define MAIN_FTDI_FT230X_USB_VENDOR_ID 0x0403
/** FTDI FT230X USB product ID. */
#define MAIN_FTDI_FT230X_USB_PRODUCT_ID 0x6015
/** FTDI EEPROM size in bytes. */
#define MAIN_FTDI_EEPROM_SIZE 2048
/* The String Descriptor Space area offset in bytes in the FTDI EEPROM. */
#define MAIN_FTDI_EEPROM_STRING_DESCRIPTOR_SPACE_OFFSET 0xA0

/** The USB manufacturer string value to set. */
#define MAIN_USB_MANUFACTURER_STRING "BayLibre"
/** The USB description string value to set. */
#define MAIN_USB_PRODUCT_STRING "BayLibre Copilot Lite V1.3"

//-------------------------------------------------------------------------------------------------
// Private functions
//-------------------------------------------------------------------------------------------------
/** Detect all connected compatible FTDI devices and make sure only one is connected.
 * @param Pointer_FTDI_Context The initialized FTDI context.
 * @param Pointer_String_USB_Serial_Number On output, will contain the USB serial number coming from factory.
 * @param Serial_Number_Buffer_Size The size in bytes of the serial number buffer.
 * @return -1 if an error occurred,
 * @return 0 on success.
 */
static int MainFindDevice(struct ftdi_context *Pointer_FTDI_Context, char *Pointer_String_USB_Serial_Number, size_t Serial_Number_Buffer_Size)
{
	struct ftdi_device_list *Pointer_Devices_List, *Pointer_Devices_List_Item;
	int Return_Value = -1, Devices_Count = 0;
	char String_Manufacturer[64], String_Description[64], String_Serial_Number[64];

	// Detect all FTDI devices from the FT-X serie
	if (ftdi_usb_find_all(Pointer_FTDI_Context, &Pointer_Devices_List, MAIN_FTDI_FT230X_USB_VENDOR_ID, MAIN_FTDI_FT230X_USB_PRODUCT_ID) < 0)
	{
		LOG("Error : could not retrieve the list of connected FTDI devices (%s).\n", ftdi_get_error_string(Pointer_FTDI_Context));
		return -1;
	}

	// Determine how many devices were found
	Pointer_Devices_List_Item = Pointer_Devices_List;
	while (Pointer_Devices_List_Item != NULL)
	{
		// Is this device a FT230X or a Copilot Lite ?
		if (ftdi_usb_get_strings(Pointer_FTDI_Context, Pointer_Devices_List_Item->dev, String_Manufacturer, sizeof(String_Manufacturer), String_Description, sizeof(String_Description), String_Serial_Number, sizeof(String_Serial_Number)) < 0)
		{
			LOG("Error : failed to get the USB strings for an USB device (%s).\n", ftdi_get_error_string(Pointer_FTDI_Context));
			goto Exit_Free_List;
		}
		if (((strcmp(String_Manufacturer, "FTDI") == 0) && (strcmp(String_Description, "FT230X Basic UART") == 0))
			|| ((strcmp(String_Manufacturer, "BayLibre") == 0) && (strncmp(String_Description, "BayLibre Copilot Lite", 21) == 0))) Devices_Count++;

		Pointer_Devices_List_Item = Pointer_Devices_List_Item->next;
	}
	printf("Found %d Copilot Lite device(s).\n", Devices_Count);

	if (Devices_Count == 0)
	{
		printf("No Copilot Lite device was found, please connect one and restart this program.\n");
		goto Exit_Free_List;
	}
	if (Devices_Count > 1)
	{
		printf("More than one Copilot Lite device was found, please connect only one device and restart this program.\n");
		goto Exit_Free_List;
	}

	// Open the found device
	if (ftdi_usb_open(Pointer_FTDI_Context, MAIN_FTDI_FT230X_USB_VENDOR_ID, MAIN_FTDI_FT230X_USB_PRODUCT_ID) < 0)
	{
		LOG("Error : could not open the found Copilot Lite device (%s).\n", ftdi_get_error_string(Pointer_FTDI_Context));
		goto Exit_Free_List;
	}

	// Store the serial number now that everything is working
	if (strlen(String_Serial_Number) >= Serial_Number_Buffer_Size)
	{
		LOG("Error : not enough room to store the USB serial number.\n");
		goto Exit_Free_List;
	}
	strcpy(Pointer_String_USB_Serial_Number, String_Serial_Number);

	// Everything went fine
	Return_Value = 0;

Exit_Free_List:
	ftdi_list_free(&Pointer_Devices_List);

	return Return_Value;
}

/** Serialize the FTDI EEPROM (configure the USB strings, the CBUS pins function, the maximum drawn power and so on.
 * @param Pointer_FTDI_Context The initialized FTDI context.
 * @param Pointer_String_USB_Serial_Number The USB serial number string to program into the device EEPROM.
 * @return -1 if an error occurred,
 * @return 0 on success.
 */
static int MainSerializeEEPROM(struct ftdi_context *Pointer_FTDI_Context, char *Pointer_String_USB_Serial_Number)
{
	int Return_Value = -1, i;

	// Fill the in-RAM EEPROM structure with the factory settings, so in the same time set the USB strings
	if (ftdi_eeprom_initdefaults(Pointer_FTDI_Context, MAIN_USB_MANUFACTURER_STRING, MAIN_USB_PRODUCT_STRING, Pointer_String_USB_Serial_Number) < 0)
	{
		LOG("Error : could not initialize the FTDI EEPROM (%s).\n", ftdi_get_error_string(Pointer_FTDI_Context));
		goto Exit_Close_Device;
	}

	// Set bus power to 500mA
	if (ftdi_set_eeprom_value(Pointer_FTDI_Context, MAX_POWER, 500) < 0)
	{
		LOG("Error : failed to set the maximum power EEPROM setting (%s).\n", ftdi_get_error_string(Pointer_FTDI_Context));
		goto Exit_Close_Device;
	}

	// Configure all 4 CBUS pins as GPIOs
	for (i = CBUS_FUNCTION_0; i < CBUS_FUNCTION_4 ; i++)
	{
		if (ftdi_set_eeprom_value(Pointer_FTDI_Context, i, CBUSX_IOMODE) < 0)
		{
			LOG("Error : failed to set the CBUS %d function EEPROM setting (%s).\n", i - CBUS_FUNCTION_0, ftdi_get_error_string(Pointer_FTDI_Context));
			goto Exit_Close_Device;
		}
	}

	// Generate the binary image to write to the EEPROM
	if (ftdi_eeprom_build(Pointer_FTDI_Context) < 0)
	{
		LOG("Error : could not build binary image for the EEPROM (%s).\n", ftdi_get_error_string(Pointer_FTDI_Context));
		goto Exit_Close_Device;
	}

	// Update the device EEPROM
	if (ftdi_write_eeprom(Pointer_FTDI_Context) < 0)
	{
		LOG("Error : failed to write EEPROM image to device (%s).\n", ftdi_get_error_string(Pointer_FTDI_Context));
		goto Exit_Close_Device;
	}

	// Everything went fine
	Return_Value = 0;

Exit_Close_Device:
	ftdi_usb_close(Pointer_FTDI_Context);

	return Return_Value;
}

//-------------------------------------------------------------------------------------------------
// Entry point
//-------------------------------------------------------------------------------------------------
int main(void)
{
	struct ftdi_context *Pointer_FTDI_Context;
	int Return_Value = EXIT_FAILURE;
	char String_USB_Serial_Number[64];

	// This program must be executed as root, otherwise some udev rules would be required
	if (getuid() != 0)
	{
		LOG("Error : this program must be run as root.\n");
		return EXIT_FAILURE;
	}

	// Initialize the FTDI library
	Pointer_FTDI_Context = ftdi_new();
	if (Pointer_FTDI_Context == NULL)
	{
		LOG("Error : failed to initialize the FTDI library (%s).\n", ftdi_get_error_string(Pointer_FTDI_Context));
		return EXIT_FAILURE;
	}

	// Check whether a single corresponding FTDI device is connected
	printf("Searching for the FTDI device to serialize...\n");
	if (MainFindDevice(Pointer_FTDI_Context, String_USB_Serial_Number, sizeof(String_USB_Serial_Number)) != 0) goto Exit_Free_Library;

	// Configure the required EEPROM settings
	printf("Serializing the device with serial number \"%s\".\n", String_USB_Serial_Number);
	if (MainSerializeEEPROM(Pointer_FTDI_Context, String_USB_Serial_Number) != 0) goto Exit_Free_Library;

	// Everything went fine
	printf("\033[32mSerialization was successful, please reset the FTDI device by disconnecting it.\033[0m\n");
	Return_Value = EXIT_SUCCESS;

Exit_Free_Library:
	ftdi_free(Pointer_FTDI_Context);
	return Return_Value;
}

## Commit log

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2023-08-25 lite: Added FTDI USB connector, power supplies and USB differential pair to schematic.
    [Controller.kicad_sch, Power_Management.kicad_sch, uCIme_Lite.kicad_sch]
2023-08-25 lite: Fixed USB-C connector 3D model alignment.
2023-08-25 lite: Added serial and USB connectors. A voltage translator is provided on the serial ports for the user to select the appropriate board voltage. No voltage translator is provided on the FTDI GPIO pi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
    [Controller.kicad_sch, Power_Management.kicad_sch, uCIme_Lite.kicad_sch]
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2023-08-25 lite: Added jumpers to control the power channel mode (always enabled, always disabled or controlled by a FTDI GPIO).
    [Controller.kicad_sch, Power_Management.kicad_sch, uCIme_Lite.kicad_sch]
2023-08-25 lite: Added leds to schematic. One led for power switch, and two for UART TX and RX.
    [Controller.kicad_sch, Power_Management.kicad_sch, uCIme_Lite.kicad_sch]
2023-08-25 lite: Added a led that lights when PC USB connector is plugged.
    [uCIme_Lite.kicad_sch]
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2023-08-25 lite: Used the +5V power supply for the power switch always-on mode instead of the +3.3V to ease routing.
    [Power_Management.kicad_sch]
2023-08-25 lite: Added a dedicated mode selection jumper per power channel. This allows to fit custom requirements, like disabling the USB power while keeping the USB connected and driving the board power with 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
    [Power_Management.kicad_sch]
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2023-08-25 lite: Added more part numbers to the schematic. Replaced the FTDI 4.7u capacitor by two 2.2u capacitors to improve the BoM.
    [Controller.kicad_sch, uCIme_Lite.kicad_sch]
2023-08-25 lite: Added to schematic all missing part numbers but the pin header ones.
    [Controller.kicad_sch, Power_Management.kicad_sch, uCIme_Lite.kicad_sch]
2023-08-25 lite: Displayed the all capacitor and resistor relevant parameters on the schematic.
    [Controller.kicad_sch, Power_Management.kicad_sch, uCIme_Lite.kicad_sch]
2023-08-25 lite: Added the PCB edge cuts and mounting holes following Raspberry Pi HATs specifications.
    See https://raw.githubusercontent.com/raspberrypi/hats/master/hat-board-mechanical.pdf.
    [uCIme_Lite.kicad_pcb, uCIme_Lite.kicad_sch]
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2023-08-25 lite: Replaced power input pins from USB-C connector by passive pins to avoid the USB-C powers being shorted in the schematic.
    [uCIme_Lite.kicad_sch]
2023-08-25 lite: Routed power USB-C High Speed and Super Speed differential pairs (without trace length matching for now).
    [uCIme_Lite.kicad_pcb]
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2023-08-25 lite: Merged serial and GPIO single-row pin headers in a double-row pin header to save some space on the PCB, only the schematic is currently updated.
    [uCIme_Lite.kicad_sch]
2023-08-25 lite: Updated serial and GPIO double-row pin header connector in PCB.
    Also moved a bit the pin headers out of the PCB to make some room for the remaining components.
    [uCIme_Lite.kicad_pcb]
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2023-08-25 lite: Merged jack and USB power modes single-row pin headers into a double-row pin header to save some space on the PCB, currently only the schematic is updated.
    [Power_Management.kicad_sch]
2023-08-25 lite: Updated jack and USB power double-row pin header connector in PCB.
    [uCIme_Lite.kicad_pcb]
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2023-08-25 lite: Routed the leds and fixed some of the PCB warnings.
    [uCIme_Lite.kicad_pcb]
2023-08-25 lite: Swapped UART RX and UART TX leds in schematic to ease PCB routing.
    [Controller.kicad_sch]
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2023-08-25 lite: Fixed all PCB warnings.
    [uCIme_Lite.kicad_pcb]
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2023-08-25 lite: Changed the serial RX and TX led names in schematic and PCB to match the previous change made to ease routing.
    [Controller.kicad_sch, uCIme_Lite.kicad_pcb]
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2023-08-25 lite: Replaced the old 'uCIme' name by the new 'Copilot' one in the board files.
    [Controller.kicad_sch, Copilot_Lite.kicad_pcb, Copilot_Lite.kicad_sch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]
2023-08-25 lite: Replaced 'From power supply' and 'To power supply' PCB texts by arrows, also fixed the maximum channel power PCB text.
    [Copilot_Lite.kicad_pcb]
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2023-08-25 lite: Replaced the TXB0104 voltage translater by several SN74LV1T125.
    The TXB0104 is not able to translate down to 1.8V on its Vccb supply side if the Vcca supply is 3.3V.
    [Controller.kicad_sch]
2023-08-25 lite: Routed the new voltage translators. PCB silkscreen is not cleaned yet.
    [Copilot_Lite.kicad_pcb]
2023-08-25 lite: Cleaned PCB silkscreen and fixed all warnings.
    [Copilot_Lite.kicad_pcb]
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2023-08-25 lite: Updated the jack and USB-C footprints in the PCB to get the component reference text on the F.Fab layer.
    [Copilot_Lite.kicad_pcb]
2023-08-25 lite: Added a little offset to the USB-C connector shield pins to make sure the connector is well aligned when being soldered.
    [Copilot_Lite.kicad_pcb]
2023-08-25 lite: Crossed the USB-C superspeed pairs and SBU signals.
    The superspeed pairs and SBU signals of an USB-C cable are crossed.
    As Copilot requires two cables, it uncrosses the signals.
    That's why Copilot needs to cross again such signals.
    [Copilot_Lite.kicad_pcb, Copilot_Lite.kicad_sch]
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2023-08-25 lite: Swapped UART and GPIO pin header rows in both schematic and PCB.
    This allows to more easily use a mezzanine board.
    It is now possible to solder a single row vertical pin header on the row
    that is located inside the PCB and a right-angled single row pin header on
    the row facing the PCB edge to still get access to the UART pins.
    This way, the GPIOs can reach the mezzanine board and there is no need to
    "forward" the UART signals to the mezzanine board.
    [Copilot_Lite.kicad_pcb, Copilot_Lite.kicad_sch]
2023-08-25 lite: Improved reading of the bottom side documentation text on PCB silkscreen.
    [Copilot_Lite.kicad_pcb]
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2023-08-25 lite: Increased the trace width between the jack connectors to dissipate more heat.
    [Copilot_Lite.kicad_pcb]
2023-08-25 lite: Added USB-C connector shell holding pins holes in paste layer.
    This way, solder paste can be directly applied also for the holding pins.
    This will help centering the connector during its soldering in the reflow oven.
    [Copilot_Lite.kicad_pcb]
2023-08-25 lite: Added even more offset to the USB-C connector shield pins to further improve its centering.
    The goal is to make sure all signal pads are well soldered even if the
    connector is placed by a human.
    [Copilot_Lite.kicad_pcb]
2023-08-25 lite: Added a little milling radius to the PCB panel to avoid PCB manufacturer warnings.
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2023-08-25 lite: Moved the hardware files to a dedicated directory to make room for a 'software' directory.
    [Controller.kicad_sch, Copilot_Lite.kicad_pcb, Copilot_Lite.kicad_sch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]
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2023-09-08 lite: hardware: Displayed the front fab layer parts reference.
    This simplifies the export of the PCB assembly PDF.
    [Copilot_Lite.kicad_pcb]
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2024-04-25 doc: getting-started: clean-up and clarify J1 header
    - Unicode characters are fun
    - Make line length consistently <= 80
    - Various small grammar fixes
    - Link to release page
    - Copilot ships with J1 configured with jumpers on 3-5 and 4-6, which
    means USB and the barrel jack are both controlled by the GPIO
    - Warning about not powering USB and barrel jacks at the same time
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2026-03-02 Copilot_Lite: Hardware: Convert the schematic and the PCB to KiCad 9
    Use the most recent files format, so any future board modification can be
    more easily compared with the previous ones.
    [Controller.kicad_sch, Copilot_Lite.kicad_pcb, Copilot_Lite.kicad_sch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]
2026-03-02 Copilot_Lite: Hardware: Increase the PCB copper to edge clearance
    It was missing before due to a misconfiguration.
    This should improve manufacturing reliability.
    [Copilot_Lite.kicad_pcb]
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2026-10-13 doc: Fix and update the UART section
